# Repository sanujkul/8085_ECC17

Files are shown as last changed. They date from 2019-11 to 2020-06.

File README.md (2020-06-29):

# 8085_ECC17
### This is project done under guidance of Prof D.V. Gadre in his lab The Centre for Electronics Design and Technology

### The aim was to make a project using 8085 microprocessor. We made a project to display location using GPS NEO 6M and required fields were displayed on the LCD.

### In this readme we will display the Project Report, so it will be lot different from actual README.md

The video demonstrating the of the project can be found at 
https://youtu.be/zBtNmY20Y-0




















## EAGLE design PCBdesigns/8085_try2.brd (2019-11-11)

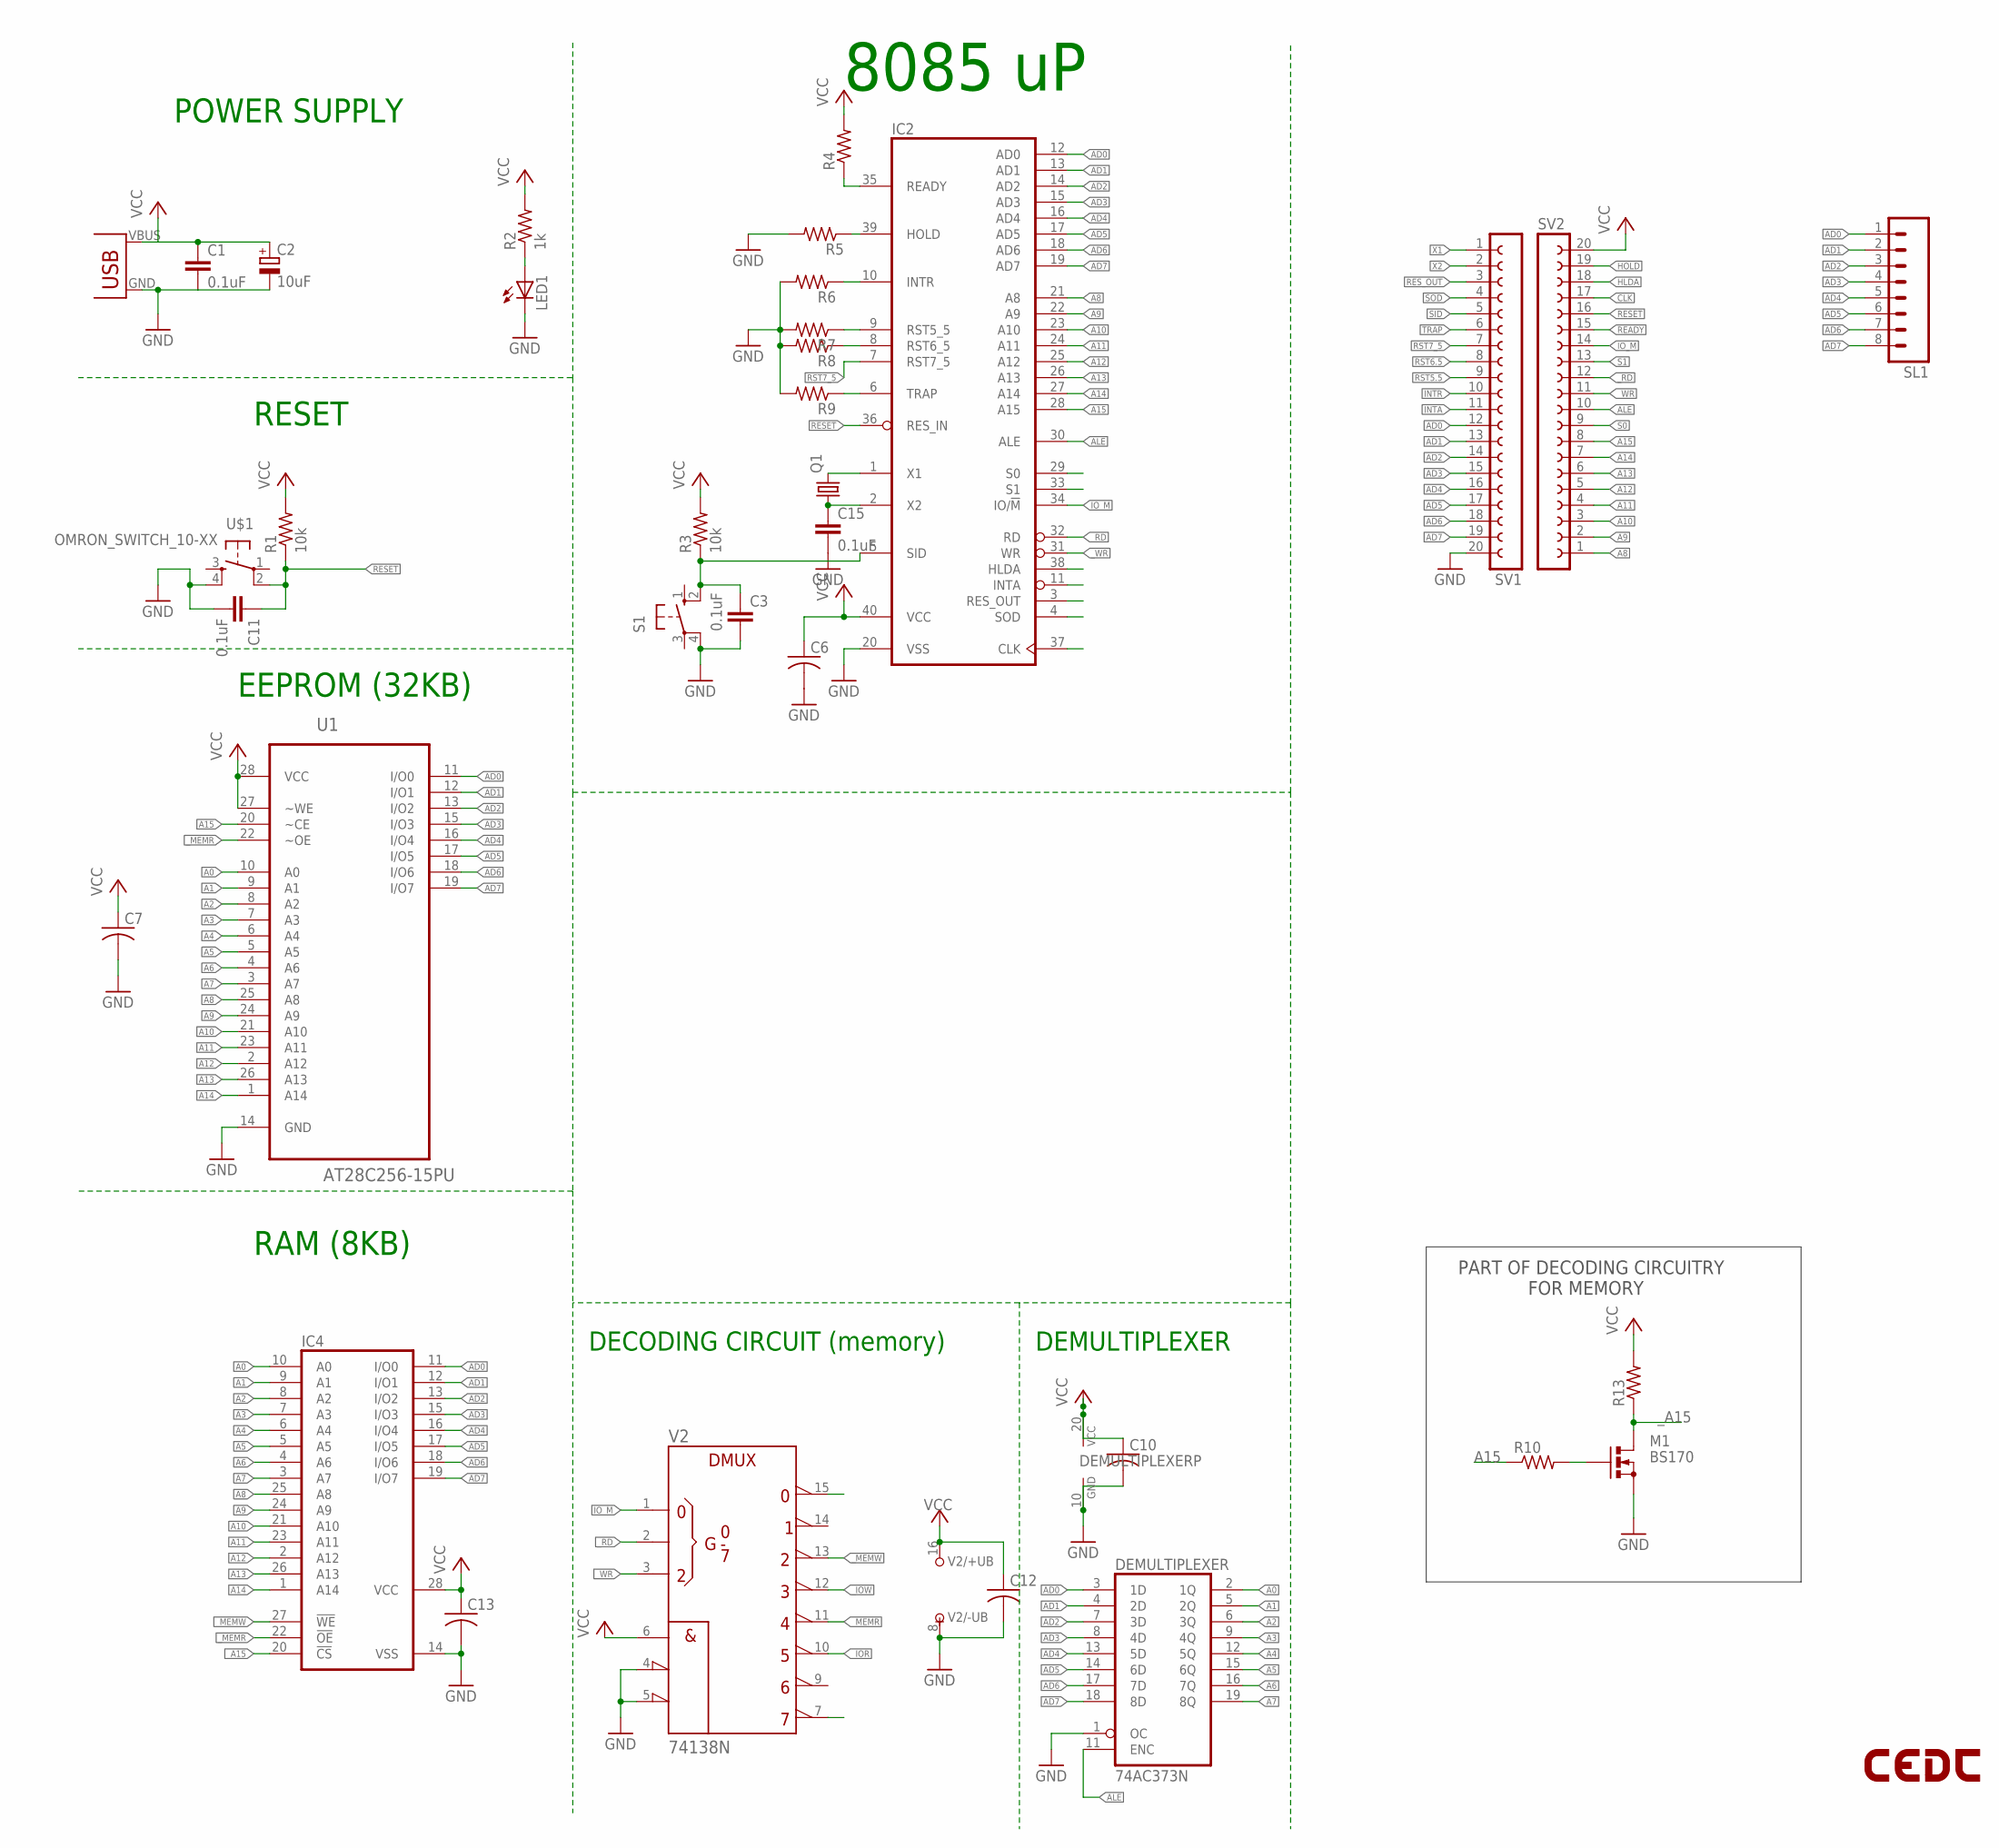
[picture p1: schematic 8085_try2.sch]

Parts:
C1, C3, C11, C15: 0.1uF; C2.5-3
C2: 10uF; E2,5-6
C6, C7, C10, C12, C13: CAP0805; C0805
DEMULTIPLEXER: 74AC373N; DIL20
IC2: 8085; DIL40
IC4: 62256P; DIL28-6
LED1: LED3MM
LOGO1: LOGO-CEDTBOT-18MM; LOGO-CEDT-BOT-18MM
M1: BS170; SOT54E
Q1: CRYSTALHC49US; HC49US
R1, R3: 10k; 0207/7
R2: 1k; 0207/7
R4, R5, R6, R7, R8, R9: RESISTOR0805; R0805
R10, R13: R-US_0204/5; 0204/5
S1: 40-XX; B3F-40XX
SL1: M08; 08P
SV1, SV2: FE20-1; FE20
U1: AT28C256-15PU; DIP254P1524X482-28
U$1: OMRON_SWITCH_10-XX; B3F-10XX
U$2: USB(POWER)
V2: 74138N; DIL16

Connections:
A0: DEMULTIPLEXER.2 (1Q), IC4.10 (A0), U1.10 (A0)
A1: DEMULTIPLEXER.5 (2Q), IC4.9 (A1), U1.9 (A1)
A2: DEMULTIPLEXER.6 (3Q), IC4.8 (A2), U1.8 (A2)
A3: DEMULTIPLEXER.9 (4Q), IC4.7 (A3), U1.7 (A3)
A4: DEMULTIPLEXER.12 (5Q), IC4.6 (A4), U1.6 (A4)
A5: DEMULTIPLEXER.15 (6Q), IC4.5 (A5), U1.5 (A5)
A6: DEMULTIPLEXER.16 (7Q), IC4.4 (A6), U1.4 (A6)
A7: DEMULTIPLEXER.19 (8Q), IC4.3 (A7), U1.3 (A7)
A8: IC2.21 (A8), IC4.25 (A8), SV2.1, U1.25 (A8)
A9: IC2.22 (A9), IC4.24 (A9), SV2.2, U1.24 (A9)
A10: IC2.23 (A10), IC4.21 (A10), SV2.3, U1.21 (A10)
A11: IC2.24 (A11), IC4.23 (A11), SV2.4, U1.23 (A11)
A12: IC2.25 (A12), IC4.2 (A12), SV2.5, U1.2 (A12)
A13: IC2.26 (A13), IC4.26 (A13), SV2.6, U1.26 (A13)
A14: IC2.27 (A14), IC4.1 (A14), SV2.7, U1.1 (A14)
A15: IC2.28 (A15), R10.1, SV2.8, U1.20 (~CE)
AD0: DEMULTIPLEXER.3 (1D), IC2.12 (AD0), IC4.11 (I/O0), SL1.1, SV1.12, U1.11 (I/O0)
AD1: DEMULTIPLEXER.4 (2D), IC2.13 (AD1), IC4.12 (I/O1), SL1.2, SV1.13, U1.12 (I/O1)
AD2: DEMULTIPLEXER.7 (3D), IC2.14 (AD2), IC4.13 (I/O2), SL1.3, SV1.14, U1.13 (I/O2)
AD3: DEMULTIPLEXER.8 (4D), IC2.15 (AD3), IC4.15 (I/O3), SL1.4, SV1.15, U1.15 (I/O3)
AD4: DEMULTIPLEXER.13 (5D), IC2.16 (AD4), IC4.16 (I/O4), SL1.5, SV1.16, U1.16 (I/O4)
AD5: DEMULTIPLEXER.14 (6D), IC2.17 (AD5), IC4.17 (I/O5), SL1.6, SV1.17, U1.17 (I/O5)
AD6: DEMULTIPLEXER.17 (7D), IC2.18 (AD6), IC4.18 (I/O6), SL1.7, SV1.18, U1.18 (I/O6)
AD7: DEMULTIPLEXER.18 (8D), IC2.19 (AD7), IC4.19 (I/O7), SL1.8, SV1.19, U1.19 (I/O7)
ALE: DEMULTIPLEXER.11 (ENC), IC2.30 (ALE), SV2.10
CLK: IC2.37 (CLK), SV2.17
GND: C1.2, C2.-, C3.2, C6.2, C7.2, C10.2, C11.2, C12.2, C13.2, C15.2, DEMULTIPLEXER.1 (OC), DEMULTIPLEXER.10 (GND), IC2.20 (VSS), IC4.14 (VSS), LED1.K (C), M1.S, R5.2, R6.2, R7.2, R8.2, R9.2, S1.4 (P1), SV1.20, U1.14 (GND), U$1.4 (S1), U$2.GND, V2.4 (!G2A), V2.5 (!G2B), V2.8 (-UB)
HLDA: IC2.38 (HLDA), SV2.18
HOLD: IC2.39 (HOLD), R5.1, SV2.19
INTA: IC2.11 (INTA), SV1.11
INTR: IC2.10 (INTR), R6.1, SV1.10
IO_M: IC2.34 (IO/!M), SV2.14, V2.1 (A)
unnamed: M1.G, R10.2
unnamed: LED1.A, R2.1
READY: IC2.35 (READY), R4.1, SV2.15
RESET: C11.1, IC2.36 (RES_IN), R1.1, SV2.16, U$1.2 (P1)
RES_OUT: IC2.3 (RES_OUT), SV1.3
RST5.5: IC2.9 (RST5_5), R7.1, SV1.9
RST6.5: IC2.8 (RST6_5), R8.1, SV1.8
RST7_5: IC2.7 (RST7_5), SV1.7
S0: IC2.29 (S0), SV2.9
S1: IC2.33 (S1), SV2.13
SID: C3.1, IC2.5 (SID), R3.1, S1.2 (S1), SV1.5
SOD: IC2.4 (SOD), SV1.4
TRAP: IC2.6 (TRAP), R9.1, SV1.6
VCC: C1.1, C2.+, C6.1, C7.1, C10.1, C12.1, C13.1, DEMULTIPLEXER.20 (VCC), IC2.40 (VCC), IC4.28 (VCC), R1.2, R2.2, R3.2, R4.2, R13.2, SV2.20, U1.27 (~WE), U1.28 (VCC), U$2.VBUS (VCC), V2.6 (G1), V2.16 (+UB)
X1: IC2.1 (X1), Q1.2, SV1.1
X2: C15.1, IC2.2 (X2), Q1.1, SV1.2
_A15: IC4.20 (!CS), M1.D, R13.1
_IOR: V2.10 (Y5)
_IOW: V2.12 (Y3)
_MEMR: IC4.22 (!OE), U1.22 (~OE), V2.11 (Y4)
_MEMW: IC4.27 (!WE), V2.13 (Y2)
_RD: IC2.32 (RD), SV2.12, V2.2 (B)
_WR: IC2.31 (WR), SV2.11, V2.3 (C)

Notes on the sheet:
8085 uP
POWER SUPPLY
RESET
EEPROM (32KB)
DECODING CIRCUIT (memory)
RAM (8KB)
DEMULTIPLEXER
PART OF DECODING CIRCUITRY FOR MEMORY

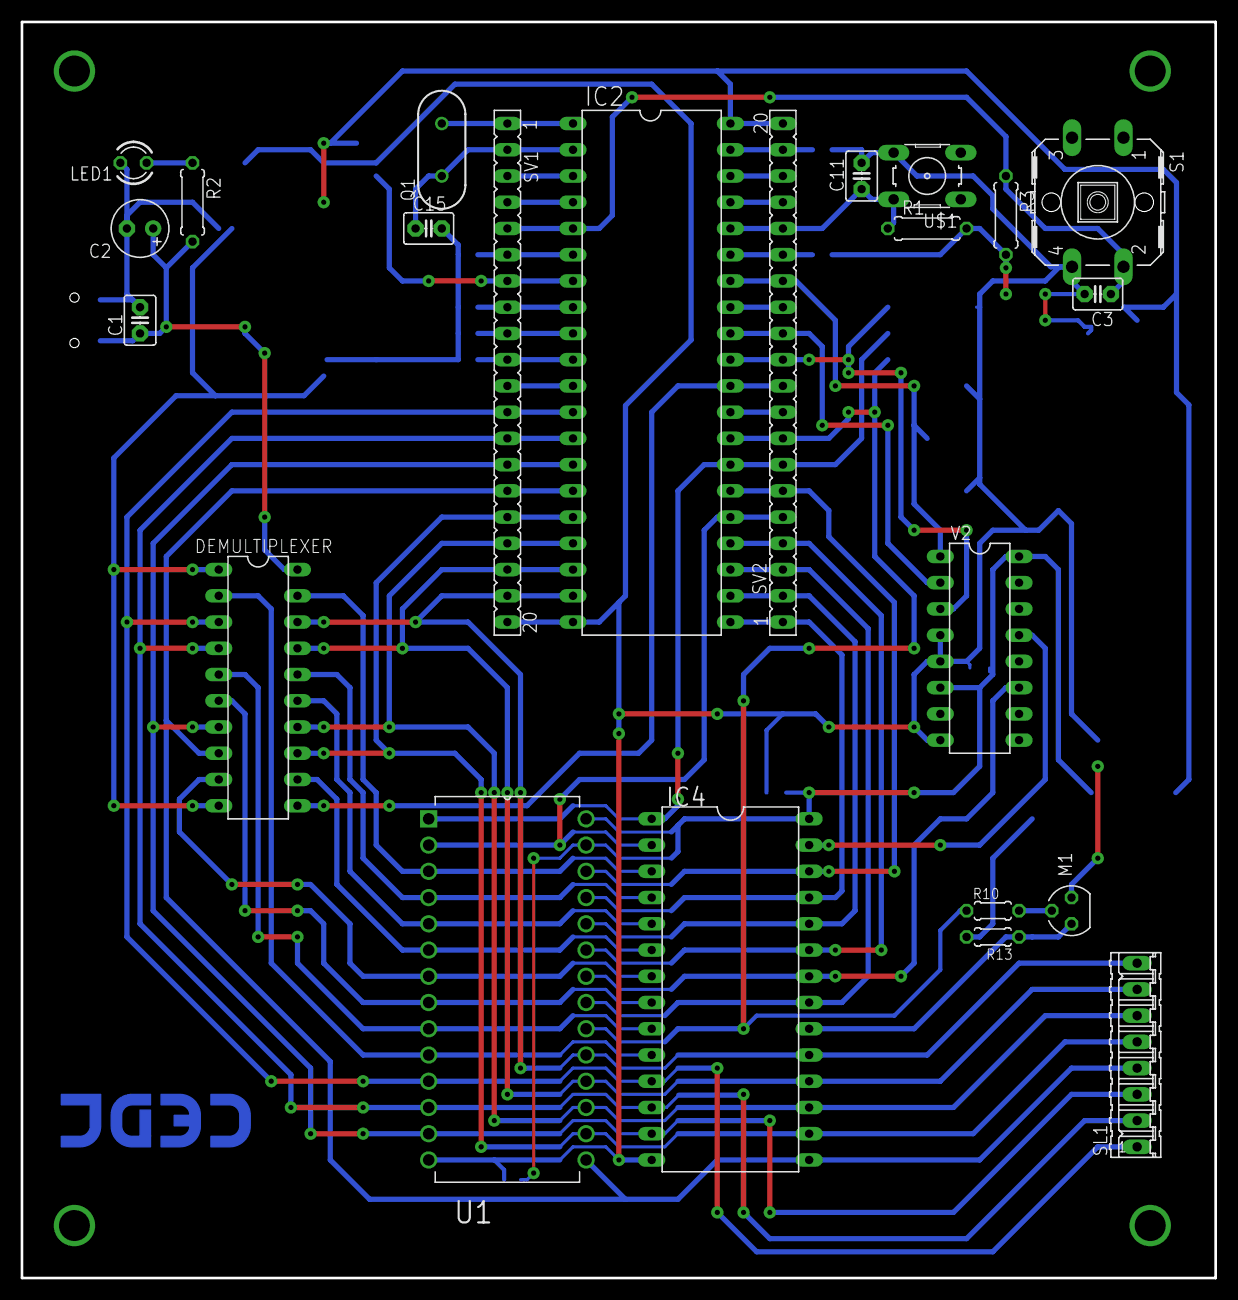
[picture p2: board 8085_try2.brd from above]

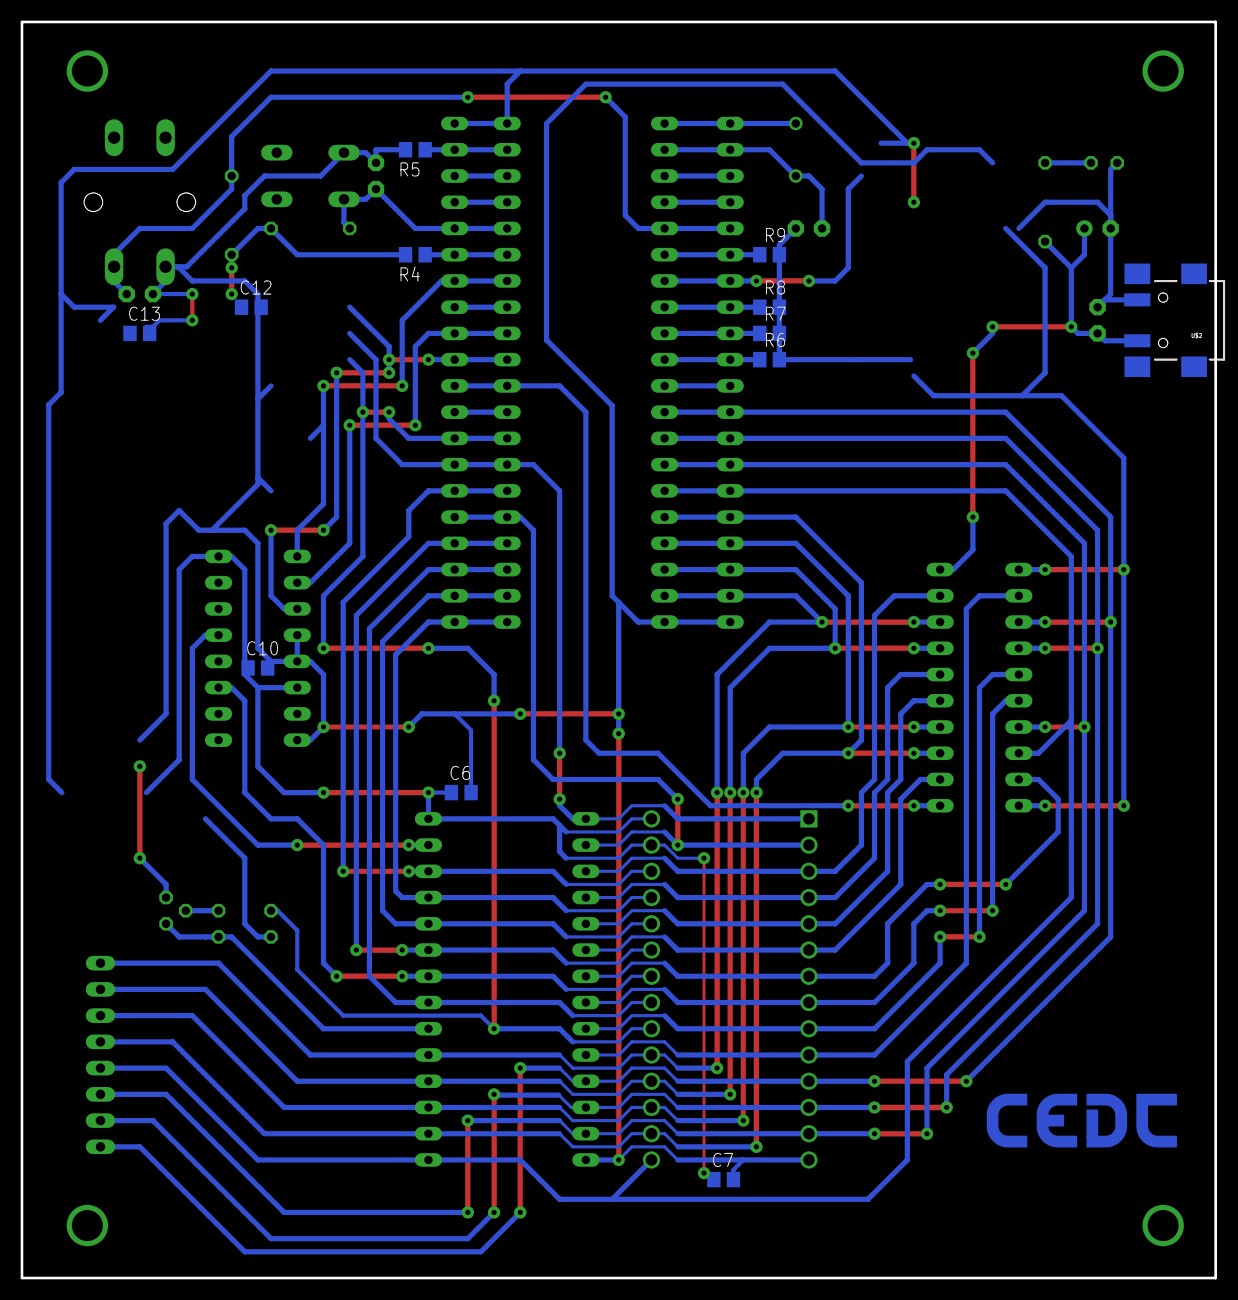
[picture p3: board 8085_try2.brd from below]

Board: 2 copper layers, 115.5 x 121.6 mm, 36 parts (12 on the bottom side), 53 nets.

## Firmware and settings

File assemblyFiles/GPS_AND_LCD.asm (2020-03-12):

# PORTA EQU 00H
# PORTB EQU 08H
# PORTC EQU 04H
# CNTRL EQU 0CH

# ORG 0000H
JMP MAIN

# ORG 003CH
JMP ISR7_5

# ORG 0500H
MAIN:	;THIS CODE INITIALIZES LCD AND 8255
	EI
	LXI SP, B000;
	MVI A, 09H;
	SIM;	

	MVI A, 80H; ALL PORTS IN OUTPUT MODE
	OUT CNTRL;
	MVI A, 00H; EN = LOW (PC0 = EN = 0)
	OUT CNTRL;

INIT:	MVI A, 30H; PRECAUTIONARY CODE
	MOV B,A; SAVE THE CODE
	CALL OUTPUT; DB7 CANT BE CHECKED WRITE NOW
	CALL CMDOUT;
	CALL CMDOUT;
	;(Actual initialisation) SETTING CONTROL REG
	MVI A, 38H;
	CALL CMDOUT;
	MVI A, 08H; Display off
	CALL CMDOUT;
	MVI A, 01H; CODE FOR CLEAR DISPLAY
	CALL CMDOUT;
	MVI A, 07H; ENTRY MODE SET; SHIFTING ON
	CALL CMDOUT;
	MVI A, 0EH; TURN ON CURSOR, DISPLAY, BLINK
	CALL CMDOUT;

DISPLAY: 	MVI A, 8FH; WRITE TO 7TH LOCATION
	CALL CMDOUT;
	MVI A, 47H;   	Print G
	CALL DTAOUT;
	MVI A, 50H;  	Print P
	CALL DTAOUT;
	MVI A, 53H;	Print S
	CALL DTAOUT;
	MVI A, 20H;	Print " "
	CALL DTAOUT;
	MVI A, 47H; `	Print G
	CALL DTAOUT;
	MVI A, 55H;	Print U
	CALL DTAOUT;
	MVI A, 49H;	Print I
	CALL DTAOUT;
	MVI A, 45H;	Print E
	CALL DTAOUT;
	MVI A, 52H;	Print R
	CALL DTAOUT
	


MAIN_LOOP: ; Doing some work like reading GPS
	LXI H, A100H;
	MVI C, 64H; COUNTER TO READ 100 BYTES
GPSREAD:	CALL SIDATA;
	MOV M,B;
	INX H;
	DCR C;
	JNZ GPSREAD;
	
	LXI H, A100H;
	MVI C, 64H; COUNTER TO READ 100 BYTES
PRINTGPS:	MOV A,M;
	CALL DTAOUT;
	INX H;
	DCR C;
	JNZ PRINTGPS;
	
	;JMP MAIN_LOOP;
	
	HLT;
;===========================================
;================LCD  FUNCTIONS===============
;===========================================
CMDOUT: 	MOV B,A; SAVE DATA BYTE
	CALL CHKDB7; CALLING CHKDB7
OUTPUT:	MVI A, 02H; Select data Reg, SETTING PC1 = RS = 0
	OUT CNTRL;
	MVI A, 04h; Enable Write, PC2 = R/W = 0;
	OUT CNTRL;
	MVI A, 01H; Set Enable HIGH
	OUT CNTRL;
	MOV A,B;    Get the data
	OUT PORTB;
	MVI A, 00H;  Set EN LOW
	OUT CNTRL;
	RET;


DTAOUT: 	CALL SCROLLDELAY
	MOV B,A; SAVE DATA BYTE
	CALL CHKDB7; CALLING CHKDB7
	MVI A, 03H; Select data Reg, SETTING PC1 = RS = 1
	OUT CNTRL;
	MVI A, 04h; Enable Write, PC2 = R/W = 0;
	OUT CNTRL;
	MVI A, 01H; Set Enable HIGH
	OUT CNTRL;
	MOV A,B;    Get the data
	OUT PORTB;
	MVI A, 00H; Set EN LOW
	OUT CNTRL;
	RET;

CHKDB7:	MVI A, 92H; Set up portB as inputPort
	OUT CNTRL
	MVI A, 02H; Seting PC1 = RS = 0;
	OUT CNTRL;
	MVI A, 05H; PC2 = R/w = 1
	OUT CNTRL;
READ:	MVI A, 01H; SET ENABLE HIGH
	OUT CNTRL;
	IN PORTB;	 READ PORTB AND CHECK DB7
	RLC; 
	MVI A, 00H;  SETTING ENABLE LOW
	OUT CNTRL;	
	JC READ;	 IF DB7=1, GO BACK AND CHECK AGAIN
	MVI A, 80H; SET UP PORTB AS OUTPUT AGAIN
	OUT CNTRL
	RET;

SCROLLDELAY: PUSH PSW;
	PUSH D;
	LXI D,7A30; FOR 250MS delay	
SCROLLDELAYLoop:
	   DCX D
	   MOV A,D
	   ORA E
	   JNZ SCROLLDELAYLoop
	POP D
	POP PSW
	   RET

;===========================================
;============= ISR ===========================
;===========================================
ISR7_5: 	PUSH PSW;
	PUSH D;
	PUSH B;
	
	MVI A, 20H;
	CALL DTAOUT;
	MVI A, 20H;
	CALL DTAOUT;
	MVI A, 20H;
	CALL DTAOUT;
	MVI A, 20H;
	CALL DTAOUT;

	POP B;
	POP D;
	POP PSW;
	EI;
	RET;

;===========================================
;============= GPS SID READ ===================
;===========================================
;FUNCTION- SID DATA
;This function returns a byte in B register, Then main function need to store it in memory
SIDATA: 	PUSH PSW;
	PUSH D;
	RIM;   Read SID Line
	RAL;   Put this bit in CY flag
	JC SIDATA; if bit = 1, this means not started
	                ;if bit = 0; this means start bit	
	CALL HAFBIT; We got start bit; wait for half bit time
	
	MVI D, 09H; Counter for 9 bits

NXTBIT: 	CALL BITTIME; Wait for 1 bit period
	RIM;
	RAL;
	DCR D;
	JZ OVER;
	
	MOV A,B;
	RAR;
	MOV B,A;
	JMP NXTBIT;

OVER:	POP D;
	POP PSW
	RET


;FUNCTION- BIT TIME
;Calling this subroutine will cause delay of 103us (incluing call)
BITTIME:    PUSH B;
	PUSH PSW;
	MVI B, 11H;
bitTimeloop: DCR B;
	   JNZ bitTimeloop

	   MVI D, D; Replacement of NOP
 	   POP PSW;
 	   POP B;
	   RET;

;FUNCTION- HAFBIT (Half bit delay)
;Calling this subroutine will cause delay of 103us (incluing call)
HAFBIT:    PUSH B;
	PUSH PSW;
	MVI B, 06H;
hafTimeloop: DCR B;
	   JNZ bitTimeloop;

	POP PSW;
	POP B;
	RET;

;===========================================
;============= DELAY ========================
;===========================================  
DELAY500:
	   LXI B,FFFF
DELAY500Loop:
	   DCX B
	   MOV A,B
	   ORA C
	   JNZ DELAY500Loop
	   RET

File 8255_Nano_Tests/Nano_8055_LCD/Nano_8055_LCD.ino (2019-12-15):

#define CS 10
#define A1 11
#define A0 12
#define WR 13

void setup() {
  for(int i=2; i<=13; i++){
    pinMode(i, OUTPUT);
  }
  digitalWrite(WR, HIGH);
}

void loop() {
// I. Setting up 8055 
  //Send 80H to CNTRL Reg of 8055: All are in output mode
  sendDataToCntrlReg("10000000"); //IO Mode
  delay(4);
  //PC0 -> HIGH, //LCD enable -> HIGH 
  sendDataToCntrlReg("00000001"); //BSR Mode

  //Testing
  //sendDataToPortB("10101000"); //Working!
// II. Setting up LCD:
  //Sending Function set
  writeToLCDCommandReg("00111000"); //38H sending 
  delay(1);
  //Display On/Off
  writeToLCDCommandReg("00001110"); //0EH sending
  delay(1);
  //Sending Entry Mode Set
  writeToLCDCommandReg("00000111"); //06H sending
  delay(1);
  //Sending Function set
  writeToLCDCommandReg("00000001"); //06H sending
  delay(1);  
  //Start writing from 8th position
  writeToLCDCommandReg("10001111");
// III. Writing Data to Data Reg
  writeToLCDDataReg("01010100");
  writeToLCDDataReg("01001000");
  writeToLCDDataReg("01001001");
  writeToLCDDataReg("01010011");
  
  writeToLCDDataReg("00100000");

  writeToLCDDataReg("01001001");
  writeToLCDDataReg("01010011");

  writeToLCDDataReg("00100000");

  writeToLCDDataReg("01000111");
  writeToLCDDataReg("01010000");
  writeToLCDDataReg("01010011");

  writeToLCDDataReg("00100000");
  
//Entry Mode set: I/D = 1-> Increment cursor, S=1 -> shift display
  //writeToLCDCommandReg("00000111");
  
  
  writeToLCDDataReg("01000111");
  writeToLCDDataReg("01010101");
  writeToLCDDataReg("01001001");
  writeToLCDDataReg("01000100");
  writeToLCDDataReg("01000101");
  writeToLCDDataReg("01010010");
  
  //againWritingSamething();
  
  while(1){
    
  }
}

void againWritingSamething(){

  //Sending Entry Mode Set
  writeToLCDCommandReg("00000111"); //06H sending
  
  writeToLCDDataReg("01010100");
  writeToLCDDataReg("01001000");
  writeToLCDDataReg("01001001");
  writeToLCDDataReg("01010011");
  
  writeToLCDDataReg("00100000");

  writeToLCDDataReg("01001001");
  writeToLCDDataReg("01010011");

  writeToLCDDataReg("00100000");

  writeToLCDDataReg("01000111");
  writeToLCDDataReg("01010000");
  writeToLCDDataReg("01010011");

  writeToLCDDataReg("00100000");
}
//////////////////////// LCD ////////////////////////////////////////
void writeToLCDDataReg(String Data){
  sendDataToPortB(Data);

  //Setting RS (PC1) LOW
  sendDataToCntrlReg("00000011"); //BSR Mode
  
  lcdCntrlSignals();

  delay(500);
}


void writeToLCDCommandReg(String Data){
  sendDataToPortB(Data);
  
  //Setting RS (PC1) LOW
  sendDataToCntrlReg("00000010"); //BSR Mode
  
  lcdCntrlSignals();
}

void lcdCntrlSignals(){
  //Setting WR (PC2) LOW
  sendDataToCntrlReg("00000100"); //BSR Mode

  delay(2);

  //Data is written by falling edge on EN pin
  sendDataToCntrlReg("00000000"); //BSR Mode
  delay(2);
  sendDataToCntrlReg("00000001"); //BSR Mode
}

//////////////////////////////////////////8255///////////////////////////////

void sendDataToPortB(String data){
  putDataOnDataBus(data);
  setPortBAddress(); 
  csAndWrite();
}

void sendDataToCntrlReg(String data){
  putDataOnDataBus(data);
  setCNTRLRegAddress(); 
  csAndWrite();
}

void csAndWrite(){
  digitalWrite(CS, LOW);
  delay(1);
  digitalWrite(WR, LOW);
  delay(4);
  digitalWrite(WR, HIGH);
  digitalWrite(CS, HIGH);
}

void setCNTRLRegAddress(){
  digitalWrite(A1,HIGH);
  digitalWrite(A0,HIGH);
}

void setPortBAddress(){
  digitalWrite(A1,LOW);
  digitalWrite(A0,HIGH);
}

void putDataOnDataBus(String data){
 int Dcount = 9;
 int dataIndex = 0; //at 0 index of string there is most significant bit

 for(Dcount=9; Dcount>=2; Dcount--){
  int d = String(data.charAt(dataIndex)).toInt();
  digitalWrite(Dcount, d);
  dataIndex++;
 }
}

void enableLCD(){
  //digitalWrite(9, LOW);
  delay(5);
  //digitalWrite(9,HIGH);
}

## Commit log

2019-11-11 Removed extra part form Apoorv's
    [8085_try2.brd, 8085_try2.sch]
2019-11-12 Trying to run board2 with nano
2020-06-29 Organised the files
    [8085_try2.brd, 8085_try2.sch]
